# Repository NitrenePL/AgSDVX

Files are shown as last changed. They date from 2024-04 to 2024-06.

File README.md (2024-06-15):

# Ag.S.D.V.X.

## 总览

- SDVX Controller
  Inspired by another repository AGEKI
- ~丐版SDVX手台~

| 主要配件  | 采购 | 数量  |
|:-----:|:---:|:---:|
| 按键 | 喵呜手台店SDVX按键一套 | 1 |
| 微动开关  | HONEYWELL V15S05-EZ025 | 6 |
| 旋转编码器 | 增量式旋转编码器400p | 2 |
| 旋钮 | 30*30全铝旋钮 | 2 |
| 主控板 | nano CH32V305 | 1 |
| 机壳 | 3D打印 | 1 |

## 更新履历

- [x] 定时器编码器模式读取旋转编码器（精度高，稳定）
- [x] USB 报告描述符修改完成
- [x] 适配spicecfg
- [x] 组装
- [ ] 改进旋钮
- [x] 添加灯带
- [x] 外壳改进
- [x] 添加灯光颜色配置接口
- [ ] 配置GUI界面

## 预览

- 机壳

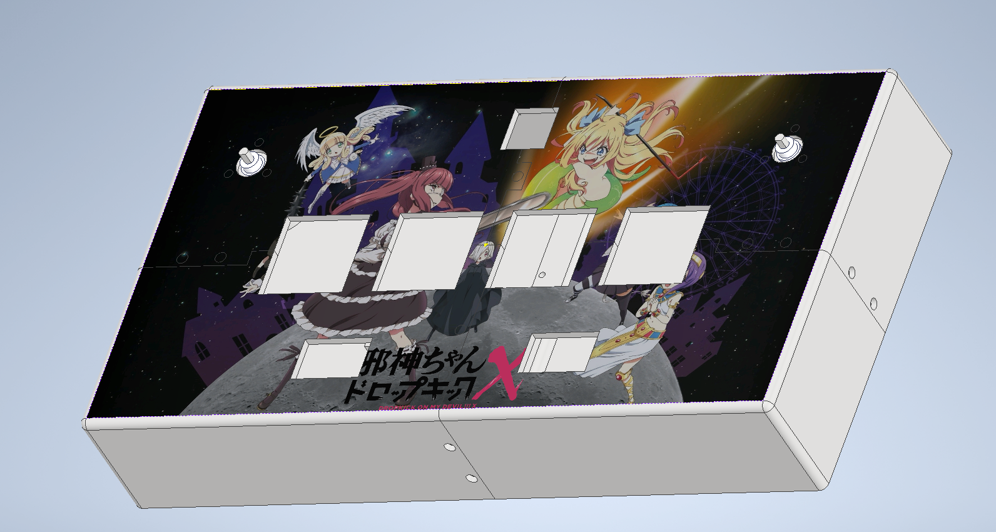
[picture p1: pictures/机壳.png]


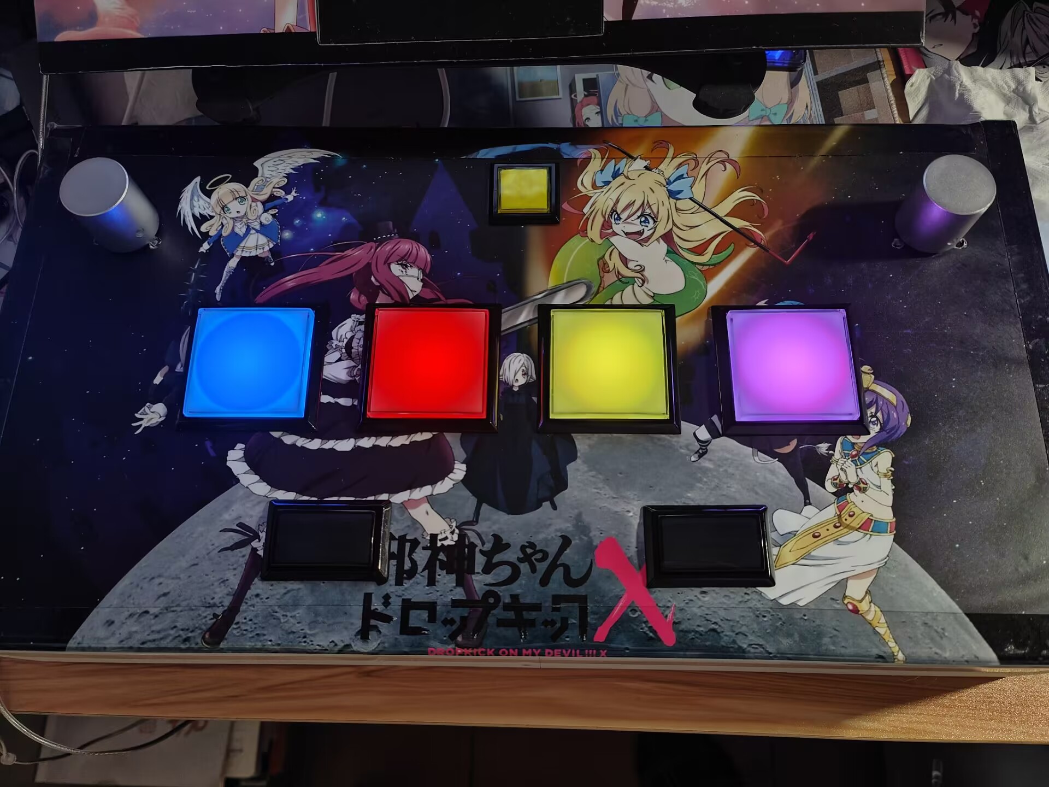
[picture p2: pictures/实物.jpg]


- 灯光配置锐意制作中

-

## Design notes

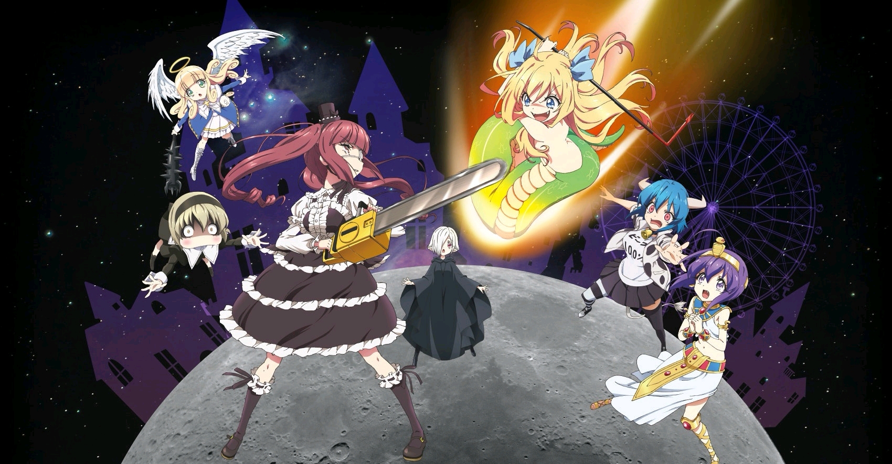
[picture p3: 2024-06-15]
pictures/jashinchan_1.jpg

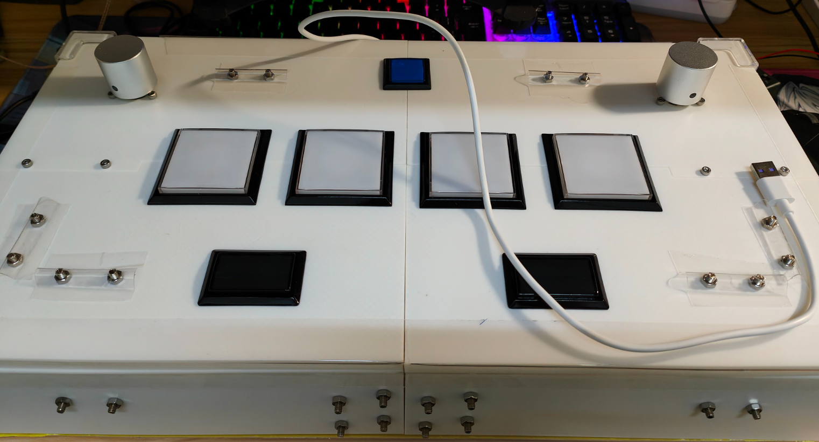
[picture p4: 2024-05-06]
pictures/台面-弃用.png

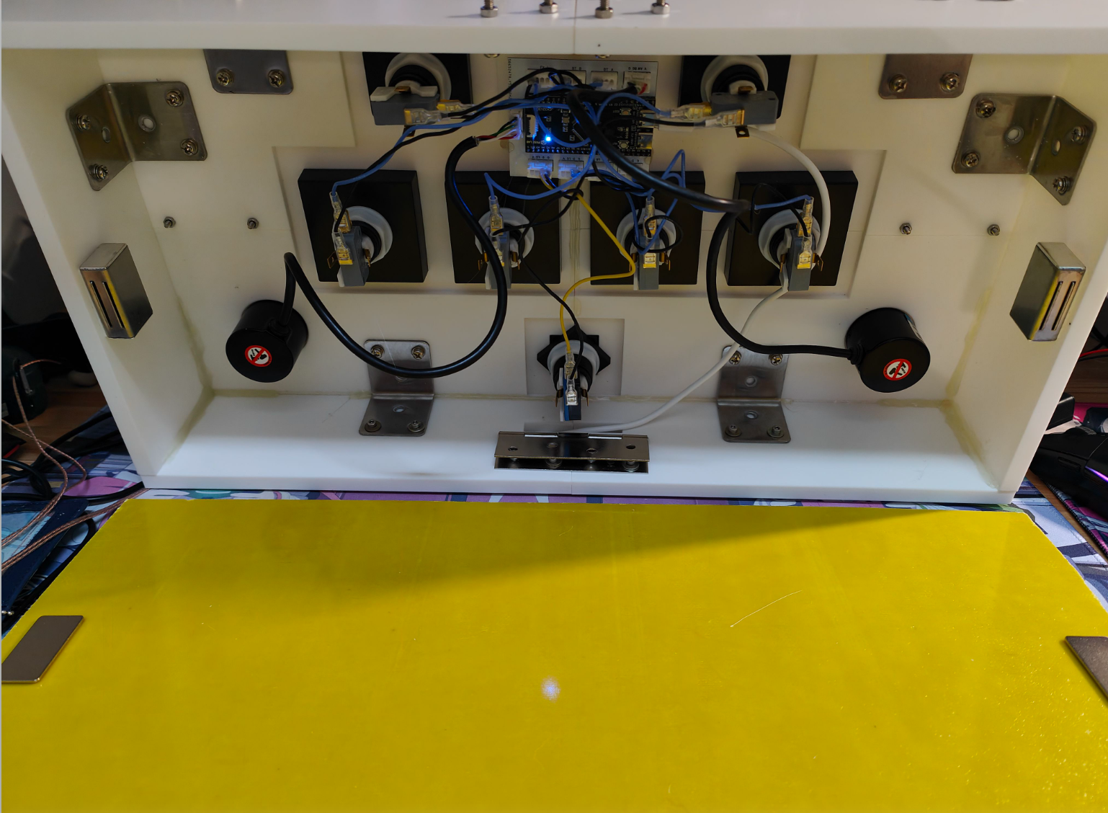
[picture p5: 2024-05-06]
pictures/内部-弃用.png

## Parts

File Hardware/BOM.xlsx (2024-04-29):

组件 | 型号 | 单价 | 数量 | 运费 | 总价
按键 | 霍尼韦尔微动 | 5.5 | 6 | 5 | 38
 | 喵呜手台店-SDVX按键 | 50 | 1 | 12 | 62
旋钮 | 增量式旋转编码器 | 24 | 2 | 0 | 48
 | 30*30全铝旋钮 | 8 | 2 | 6 | 22
外壳 | 3D打印机壳 | 0 | 1 | 0 | 0
 | 磁吸 | 8 | 2 | 0 | 16
主控板 | CH32V305 | 39.8 | 1 | 3 | 42.8
 | PCB | 20 | 1 | 0 | 20
 |  |  |  |  | 248.8

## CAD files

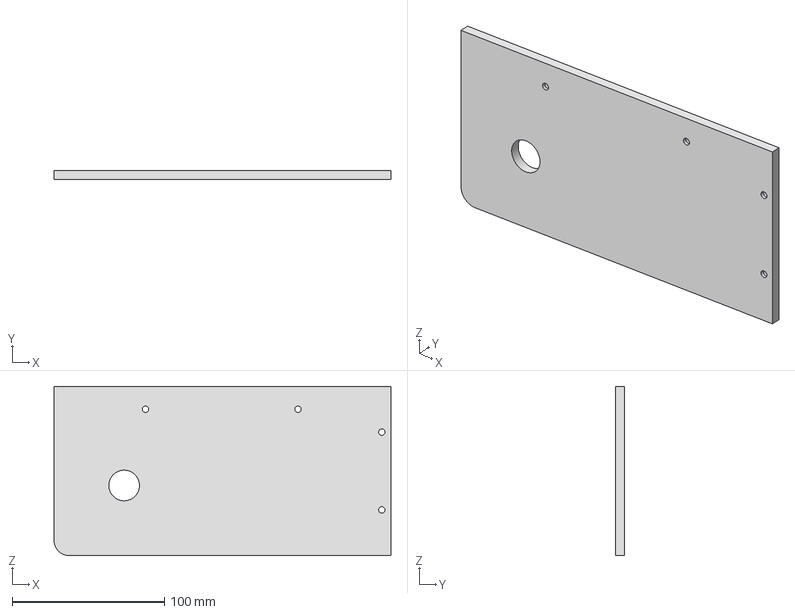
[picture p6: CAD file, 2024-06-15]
Hardware/3dprint/step/底板_D.stp
221.0 x 6.00 x 111.0 mm

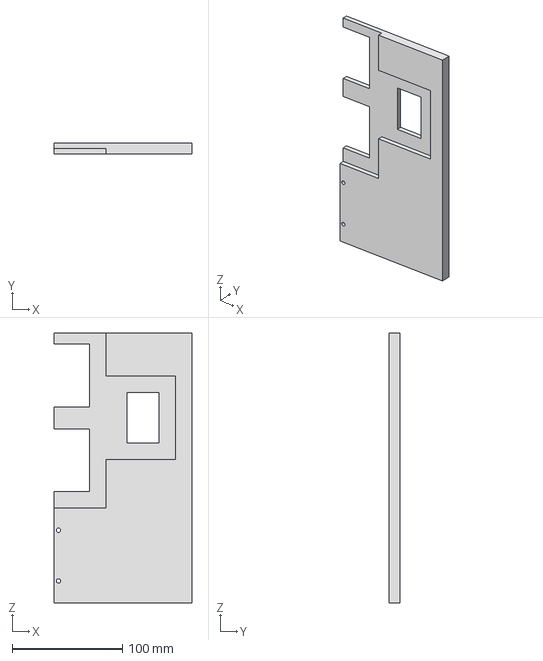
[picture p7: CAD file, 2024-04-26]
Hardware/Case/3dprint/step/top_4.stp
125.0 x 10.0 x 245.0 mm

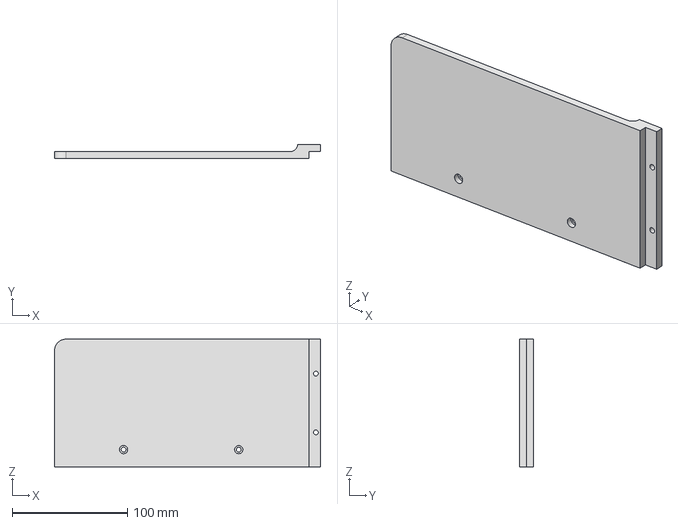
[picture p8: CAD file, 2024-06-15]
Hardware/3dprint/step/底板_A.stp
231.0 x 12.0 x 111.0 mm

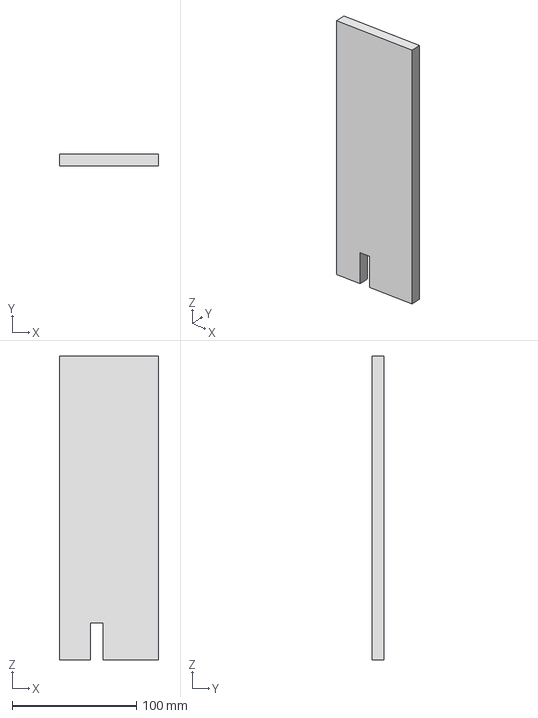
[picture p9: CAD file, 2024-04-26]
Hardware/Case/3dprint/step/back_1.stp
80.0 x 10.0 x 245.0 mm

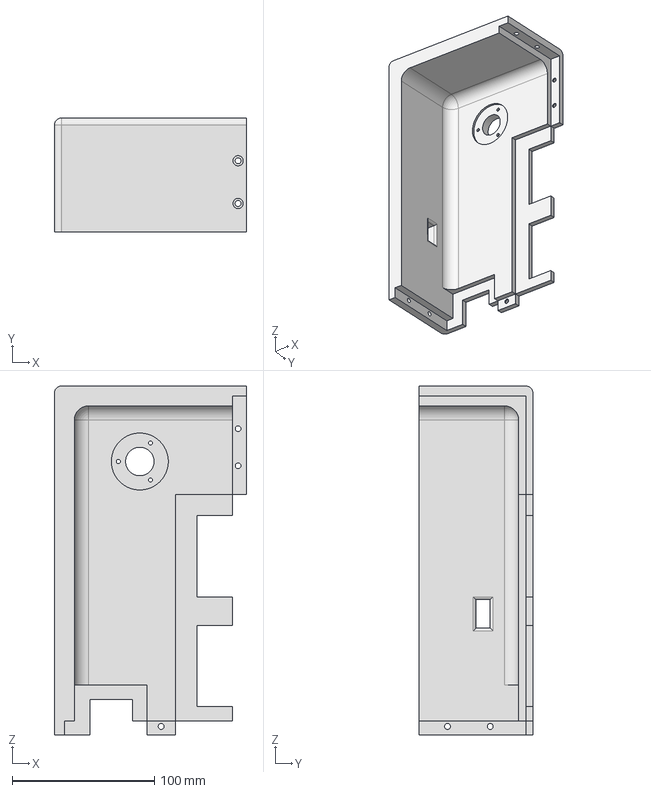
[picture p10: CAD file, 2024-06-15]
Hardware/3dprint/step/top_A.stp
135.0 x 80.0 x 245.0 mm

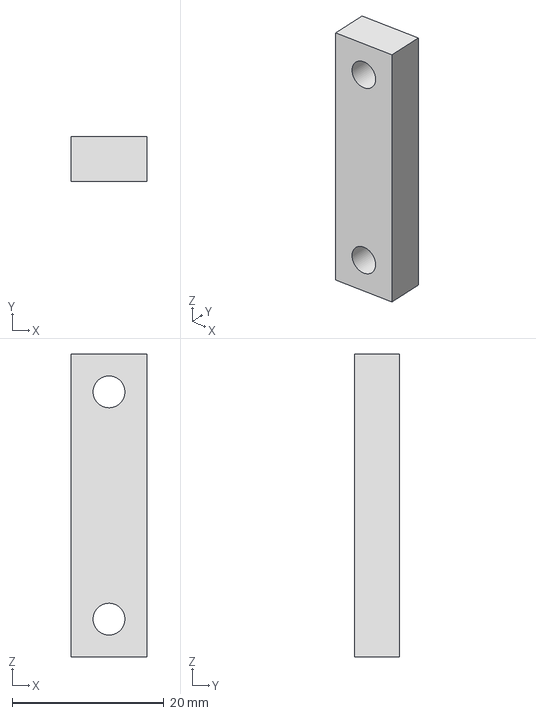
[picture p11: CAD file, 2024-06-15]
Hardware/3dprint/step/connect.stp
10.0 x 6.00 x 40.0 mm

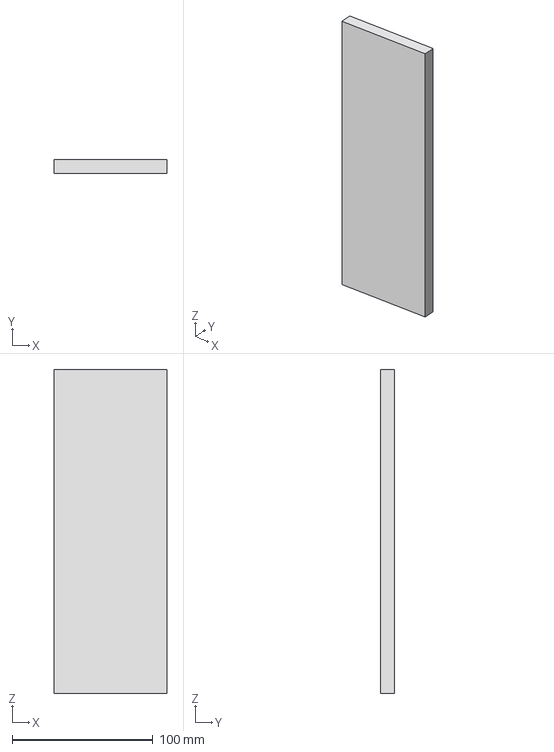
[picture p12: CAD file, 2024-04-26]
Hardware/Case/3dprint/step/right.stp
80.0 x 10.0 x 230.0 mm

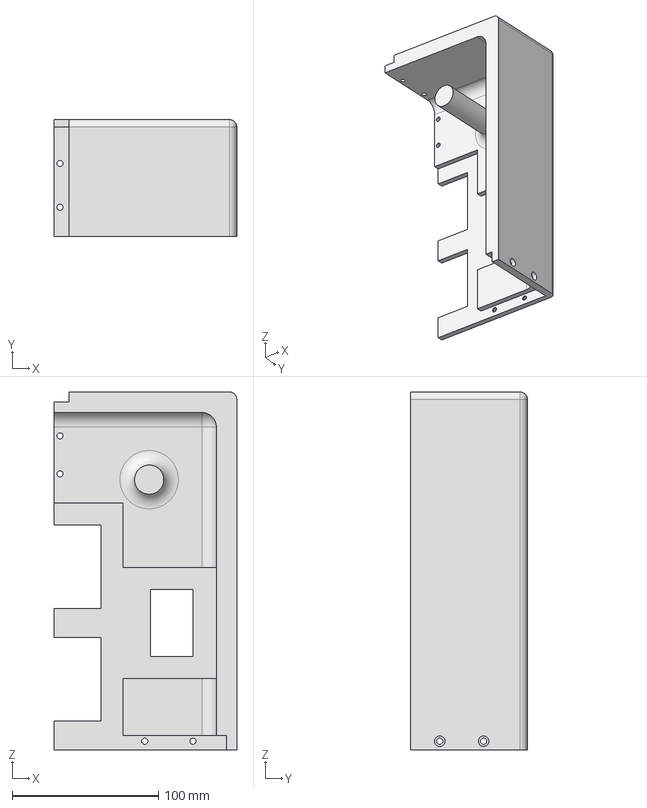
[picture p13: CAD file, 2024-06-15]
Hardware/3dprint/step/top_C.stp
125.0 x 80.0 x 245.0 mm

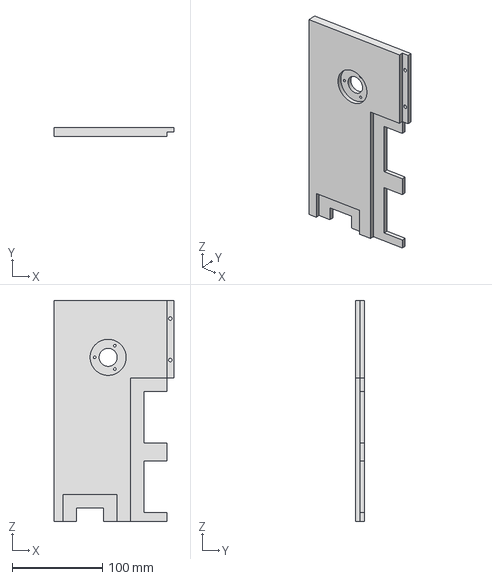
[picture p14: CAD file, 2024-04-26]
Hardware/Case/3dprint/step/top_1.stp
133.0 x 10.0 x 245.0 mm

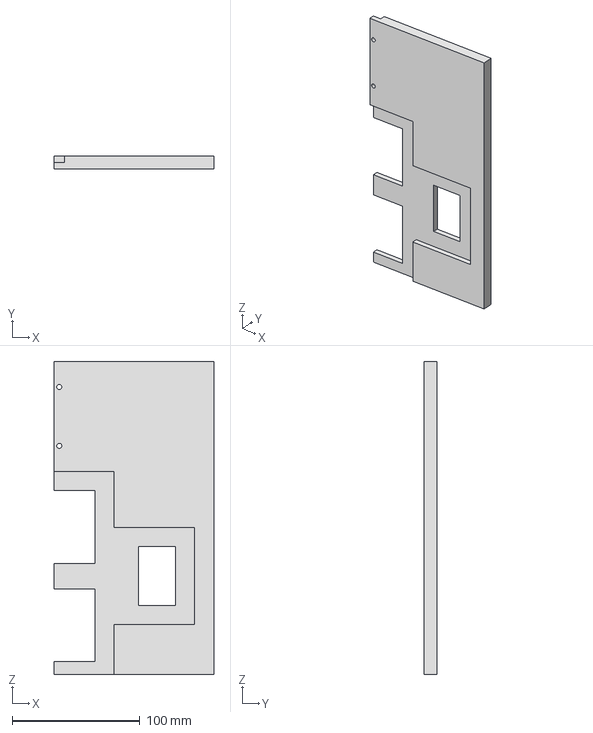
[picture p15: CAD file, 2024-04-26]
Hardware/Case/3dprint/step/top_3.stp
125.0 x 10.0 x 245.0 mm

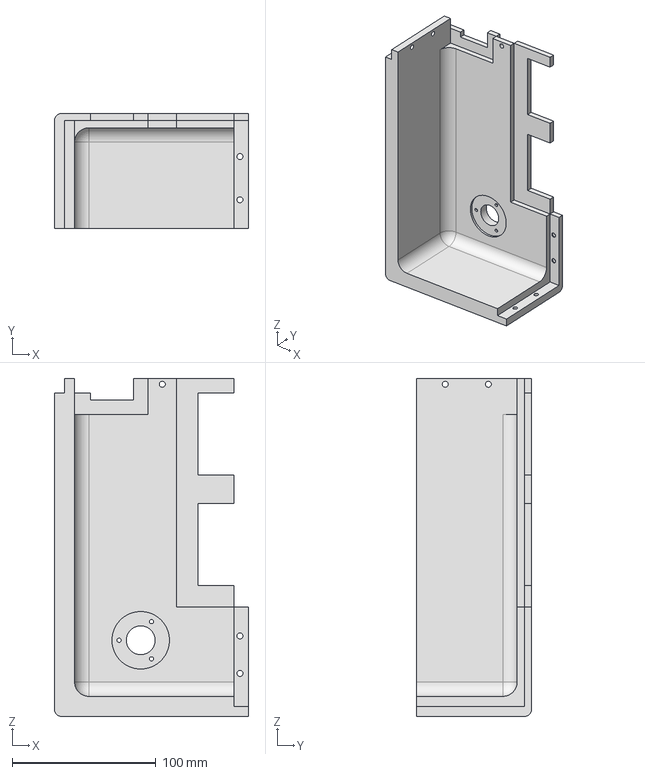
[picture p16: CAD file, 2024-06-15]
Hardware/3dprint/step/top_B.stp
135.0 x 80.0 x 235.0 mm

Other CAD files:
Hardware/Case/3dprint/step/front_1.stp
Hardware/3dprint/step/底板_C.stp
Hardware/Case/3dprint/step/front_2.stp
Hardware/3dprint/step/底板_B.stp
Hardware/Case/3dprint/step/back_2.stp
Hardware/3dprint/step/top_D.stp
Hardware/Case/3dprint/step/top_2.stp
Hardware/Case/3dprint/step/left.stp
Hardware/Case/3dprint/stl/back_1.stl
Hardware/Case/3dprint/stl/back_2.stl
Hardware/Case/3dprint/stl/front_1.stl
Hardware/Case/3dprint/stl/front_2.stl
Hardware/Case/3dprint/stl/left.stl
Hardware/Case/3dprint/stl/right.stl
Hardware/Case/3dprint/stl/top_1.stl
Hardware/Case/3dprint/stl/top_2.stl
Hardware/Case/3dprint/stl/top_3.stl
Hardware/Case/3dprint/stl/top_4.stl
Hardware/Case/Assemble.iam
Hardware/Case/OldVersions/Assemble.0017.iam
Hardware/Case/OldVersions/back_1.0002.ipt
Hardware/Case/OldVersions/back_2.0002.ipt
Hardware/Case/OldVersions/front_1.0002.ipt
Hardware/Case/OldVersions/front_2.0001.ipt
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

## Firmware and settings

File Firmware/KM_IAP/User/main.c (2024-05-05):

/********************************** (C) COPYRIGHT *******************************
* File Name          : main.c
* Author             : WCH
* Version            : V1.0.0
* Date               : 2021/06/06
* Description        : Main program body.
*********************************************************************************
* Copyright (c) 2021 Nanjing Qinheng Microelectronics Co., Ltd.
* Attention: This software (modified or not) and binary are used for 
* microcontroller manufactured by Nanjing Qinheng Microelectronics.
*******************************************************************************/

/*
 *@Note
IAP upgrade routine:
Support serial port and USB for FLASH burning

1. Use the IAP download tool to realize the download PA0 floating (default pull-up input)
2. After downloading the APP, connect PA0 to ground (low level input), and press the reset
button to run the APP program.
Note: FLASH operation keeps the frequency below 100Mhz, it is recommended that the main
frequency of IAP be below 100Mhz

*/

#include "debug.h"
#include "ch32v30x_usbotg_device.h"
#include "ch32v30x_usbhs_device.h"
#include "ch32v30x_gpio.h"
#include "iap.h"
extern u8 End_Flag;
/*********************************************************************
 * @fn      IAP_2_APP
 *
 * @brief   IAP_2_APP program.
 *
 * @return  none
 */
void IAP_2_APP(void)
{
    USBHS_Device_Init( DISABLE );
    NVIC_DisableIRQ( USBHS_IRQn );
    USBHSD->HOST_CTRL=0x00;
    USBHSD->CONTROL=0x00;
    USBHSD->INT_EN=0x00;
    USBHSD->ENDP_CONFIG=0xFFffffff;
    USBHSD->CONTROL&=~USBHS_DEV_PU_EN;
    USBHSD->CONTROL|=USBHS_ALL_CLR|USBHS_FORCE_RST;
    USBHSD->CONTROL=0x00;
    USBOTG_FS->BASE_CTRL=0x06;
    USBOTG_FS->INT_EN=0x00;
    Delay_Ms(50);
    printf("jump APP\r\n");
    GPIO_DeInit(GPIOA);
    GPIO_DeInit( GPIOB);
    USART_DeInit(USART3);
    RCC_APB2PeriphClockCmd(RCC_APB2Periph_GPIOA, DISABLE);
    RCC_APB2PeriphClockCmd( RCC_APB2Periph_GPIOB,DISABLE);
    RCC_APB1PeriphClockCmd(RCC_APB1Periph_USART3,DISABLE);
    RCC_AHBPeriphClockCmd(RCC_AHBPeriph_USBHS, DISABLE);
    RCC_AHBPeriphClockCmd(RCC_AHBPeriph_OTG_FS, DISABLE);
    Delay_Ms(10);
    NVIC_DisableIRQ(OTG_FS_IRQn);
    NVIC_EnableIRQ(Software_IRQn);
    NVIC_SetPendingIRQ(Software_IRQn);
}
/*********************************************************************
 * @fn      main
 *
 * @brief   Main program.
 *
 * @return  none
 */
int main(void)
{

	SystemCoreClockUpdate();
	Delay_Init();
	USART_Printf_Init(115200);	
	printf("SystemClk:%ld\r\n",SystemCoreClock);
	printf( "ChipID:%08lx\r\n", DBGMCU_GetCHIPID() );
    if(PA0_Check() == 0)
    {
        IAP_2_APP();
        while(1);
    }
    USART3_CFG(57600);
    /* USB20 device init */
    USBHS_RCC_Init( );
    USBHS_Device_Init( ENABLE );
    NVIC_EnableIRQ( USBHS_IRQn );

    USBOTG_Init( );
	while(1)
	{

        if( USART_GetFlagStatus(USART3, USART_FLAG_RXNE) != RESET){

            UART_Rx_Deal();
        }
        IWDG_ReloadCounter();
        if (End_Flag)
         {
             Delay_Ms(10);
             IAP_2_APP();
             while(1);
         }
	}
}

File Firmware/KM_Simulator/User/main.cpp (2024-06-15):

#include "debug.h"
#include "stdbool.h"
#include "usb_dc.h"
#include "usbd_core.h"
#include "hid_keyboard_template.h"
#include "light.hpp"
#include "controller.hpp"

extern volatile u8 Scan_Key_Status[7];
extern volatile s16 counter;

extern "C" void usb_dc_low_level_init(void)
{
    RCC_USBCLK48MConfig(RCC_USBCLK48MCLKSource_USBPHY);
    RCC_USBHSPLLCLKConfig(RCC_HSBHSPLLCLKSource_HSE);
    RCC_USBHSConfig(RCC_USBPLL_Div2);
    RCC_USBHSPLLCKREFCLKConfig(RCC_USBHSPLLCKREFCLK_4M);
    RCC_USBHSPHYPLLALIVEcmd(ENABLE);

    RCC_AHBPeriphClockCmd(RCC_AHBPeriph_USBHS, ENABLE);
    NVIC_EnableIRQ(USBHS_IRQn);

    RCC_AHBPeriphClockCmd(RCC_AHBPeriph_OTG_FS, ENABLE);
    // EXTEN->EXTEN_CTR |= EXTEN_USBD_PU_EN;
    NVIC_EnableIRQ(OTG_FS_IRQn);

    printf("usb init\n");

    Delay_Us(100);
}

extern "C" void usb_hc_low_level_init(void)
{
#ifdef CH32V30x_D8C
    RCC_USBCLK48MConfig(RCC_USBCLK48MCLKSource_USBPHY);
    RCC_USBHSPLLCLKConfig(RCC_HSBHSPLLCLKSource_HSE);
    RCC_USBHSConfig(RCC_USBPLL_Div2);
    RCC_USBHSPLLCKREFCLKConfig(RCC_USBHSPLLCKREFCLK_4M);
    RCC_USBHSPHYPLLALIVEcmd(ENABLE);
    RCC_AHBPeriphClockCmd(RCC_AHBPeriph_USBHS, ENABLE);
#else
    if (SystemCoreClock == 144000000) {
        RCC_OTGFSCLKConfig(RCC_OTGFSCLKSource_PLLCLK_Div3);
    } else if (SystemCoreClock == 96000000) {
        RCC_OTGFSCLKConfig(RCC_OTGFSCLKSource_PLLCLK_Div2);
    } else if (SystemCoreClock == 48000000) {
        RCC_OTGFSCLKConfig(RCC_OTGFSCLKSource_PLLCLK_Div1);
    }
#endif
    RCC_AHBPeriphClockCmd(RCC_AHBPeriph_OTG_FS, ENABLE);
    NVIC_EnableIRQ(OTG_FS_IRQn);
    NVIC_EnableIRQ(USBHS_IRQn);
    static uint32_t wait_ct = 20000;
    while (wait_ct--) {
    }
}

int main(void)
{
    NVIC_PriorityGroupConfig(NVIC_PriorityGroup_2);
    SystemCoreClockUpdate();
    Delay_Init();
    USART_Printf_Init(115200);

    /* Initialize GPIO for keyboard scan */
    KB_Scan_Init();
    printf("KB Scan OK!\r\n");

    /* Initialize timer for USB report*/
    TIM3_Init(1, SystemCoreClock / 10000 - 1);
    printf("TIM3 for USB OK!\r\n");

    // /* Initialize timer for Rainbow LED control*/
    // TIM2_Init(1000 - 1, 14400 - 1); // 1ms
    // printf("TIM2 for LED OK!\r\n");

    // /* Initialize USBHD interface to communicate with the host  */
    // USBHS_RCC_Init();
    // USBHS_Device_Init(ENABLE);

    /* Initialize Rotary_encoder */
    Rotary_TIM_Init();
    printf("Rotary OK!\r\n");

    /* Initialize SPI Half-Duplex-Mode for transmitting data to LED*/
    SPI2_HD_Init();
    printf("SPI2 HD OK!\r\n");

    /* Initialize WS2812b*/
    TranscendLights_Init();
    printf("TranscendLights OK!\r\n");

    printf("CherryUSB device hid keyboard example\n");

    hid_init(0, USBHS_BASE);

    while (!usb_device_is_configured(0)) {
    }

    printf("usb done\n");

    while (1) {
        Rotary_TIM_Scan();
        // KB_Scan();

        BTN_Scan();

    }
}

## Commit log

2024-05-05 try IAP
    想直接通过软件层面下载程序并更新固件，目前绝赞崩溃中
    [100ask-openjtag.cfg, 8devices-lima.cfg, actux3.cfg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]
2024-05-05 little bug fix
    现在spicecfg可以识别到各个按键了
    [controller.hpp]
2024-05-06 图片更新
2024-05-07 Rainbow Light
    添加了彩虹渐变灯
2024-05-08 整理
    调整了一些格式细节
2024-05-10 debounce
    做了一点去抖，核心频率是144MHz, 去抖计数DEBOUNCE_CHECKS设定为1440,可以根据手感情况修改
2024-06-15 Update 2.0
    全面更新
    [Assembly.0089.iam, Assembly.iam, adder.0001.ipt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]
